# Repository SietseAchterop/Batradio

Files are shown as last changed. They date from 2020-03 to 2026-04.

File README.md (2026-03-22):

# Batradio
Software defined radio on rpi zero

The goal of this project is to create a simple sdr using a rpi-zero and a simple hat.
It should work to up to 150kHz, to be used as a ULF radio or bat detector.

## Hat for raspberry Pi

### batradio_pcb
contains a KiCad project for a hat for the rpi (zero).
It contains a 1Mbit 16 bit spi adc, mcp33131 and a 14 bit dac, mcp4821.
Also a preamplifier and lowpass filter.

Status: The prototype had the following error in the PCB design. Pins 1 and 8 of the U4, a ths4521, should be swapped and a 100nF capacitor to ground should be connected to pin 2.
This, untested, version corrects that.

Here the Schematic

And the PCB
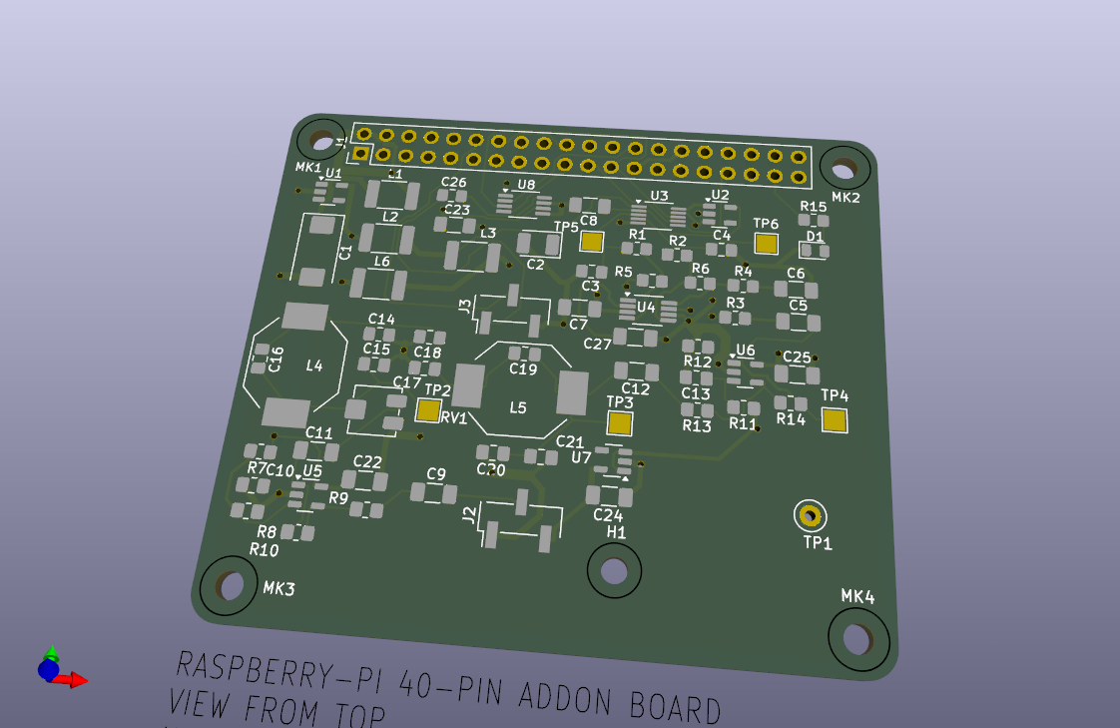
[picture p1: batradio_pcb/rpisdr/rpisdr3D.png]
PCBview


## Kernel module, a failed attempt.

Kernel module to process the data from adc and dac.
This also is work in progress.
Currently I have not been able to get the FIQ interrupt working.

### mcp331131_streaming

A variant of https://iosoft.blog/2020/11/16/streaming-analog-data-raspberry-pi/

The main changes for the 16 bit mcp33131 are:

  - Used PWM to create the CNVST pulse.
  - Writing dummy to create SCLK.
  - added -U option to send data over UDP channel.
  - DAC not used yet.
  
Basically works, but the data is partly wrong.
Also the SPI clock should be lower than 5 MHz?

## kicadlibs
My local symbols and footprints for KiCad

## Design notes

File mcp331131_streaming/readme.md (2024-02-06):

Raspberry Pi ADC data streaming

See https://iosoft.blog/streaming-analog-data-raspberry-pi for details.

This is a version using mcp33131 as ADC.
CNVCS is connected to GPIO13, PWM1
But should be GPIO12, PWM0. Forgotten why.

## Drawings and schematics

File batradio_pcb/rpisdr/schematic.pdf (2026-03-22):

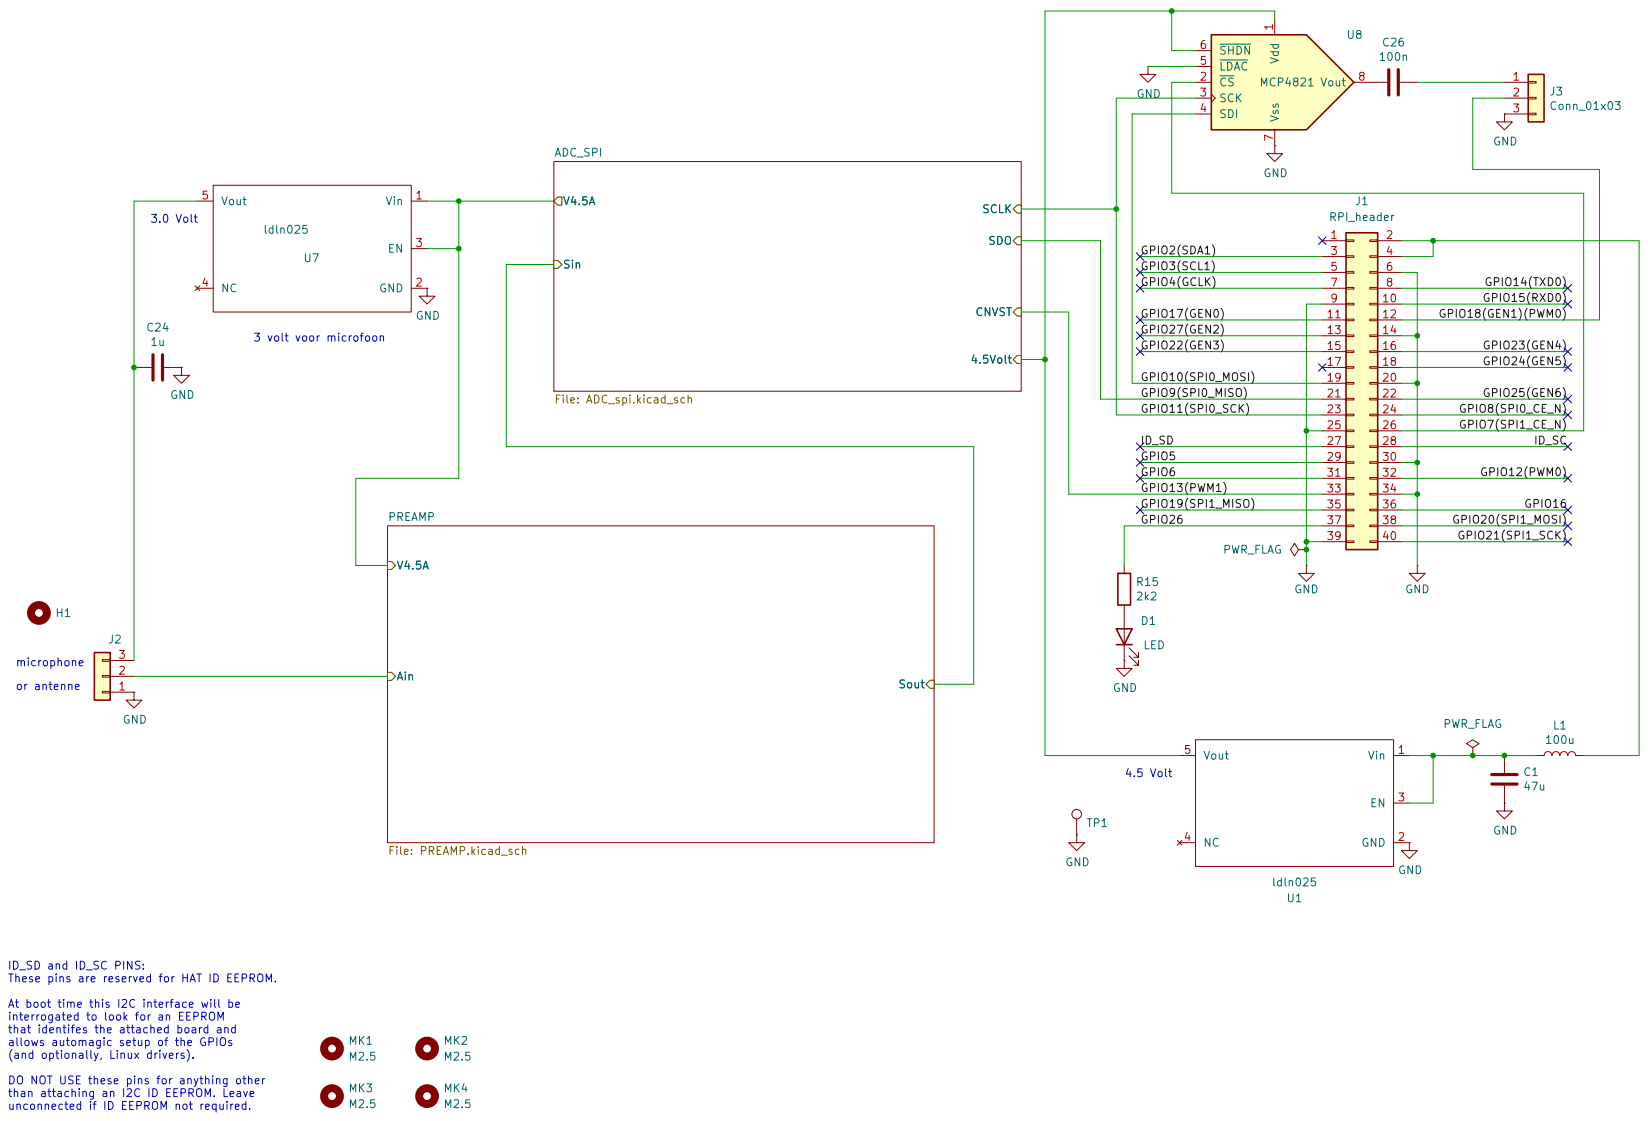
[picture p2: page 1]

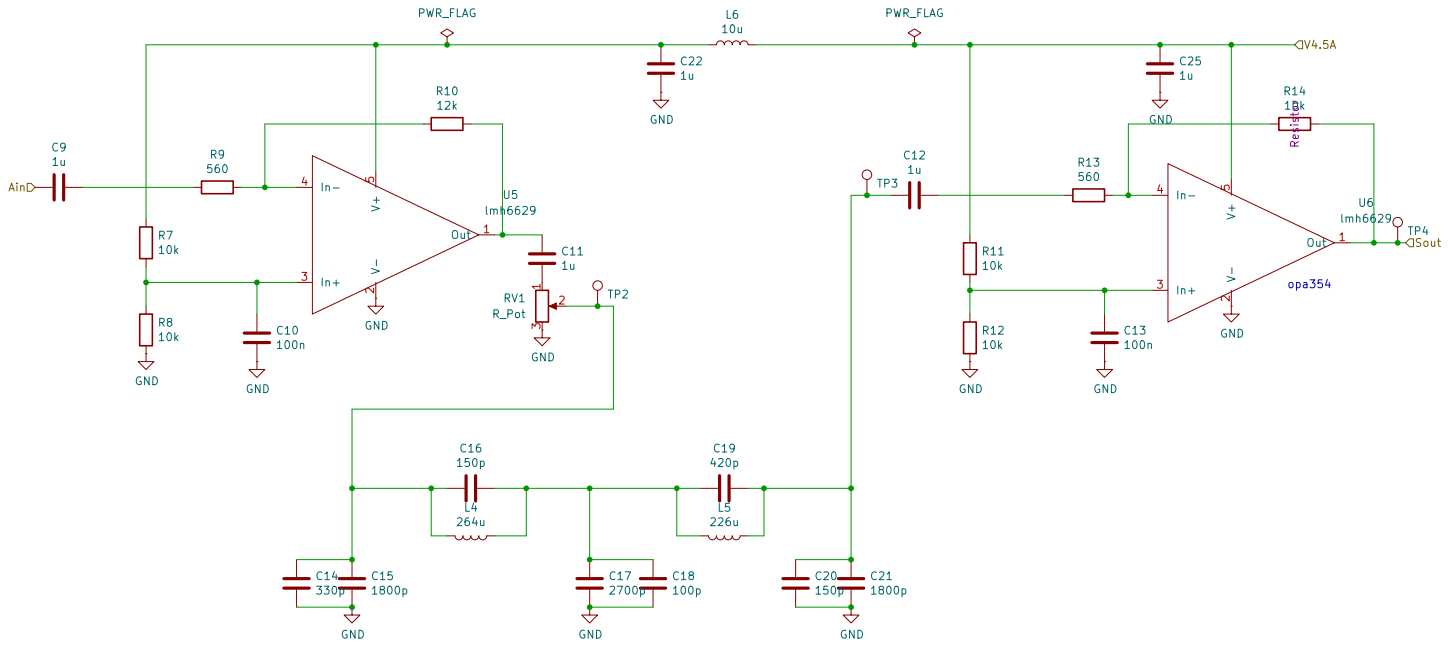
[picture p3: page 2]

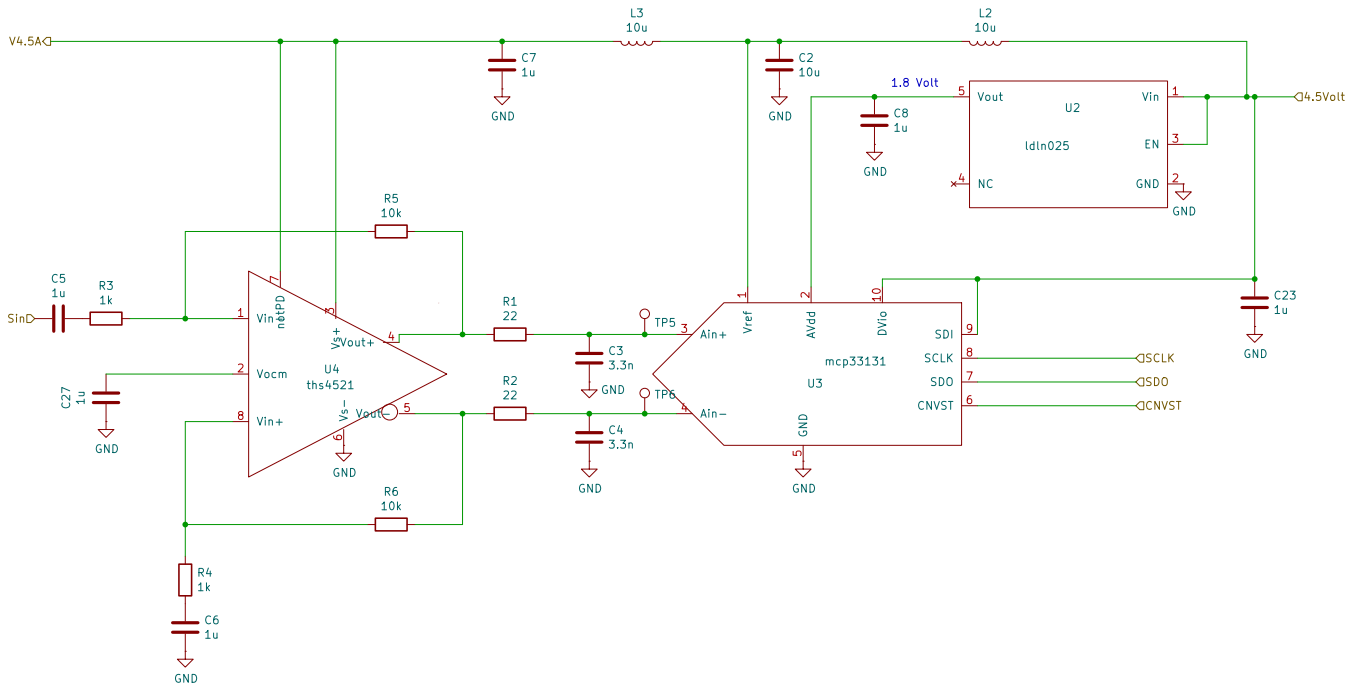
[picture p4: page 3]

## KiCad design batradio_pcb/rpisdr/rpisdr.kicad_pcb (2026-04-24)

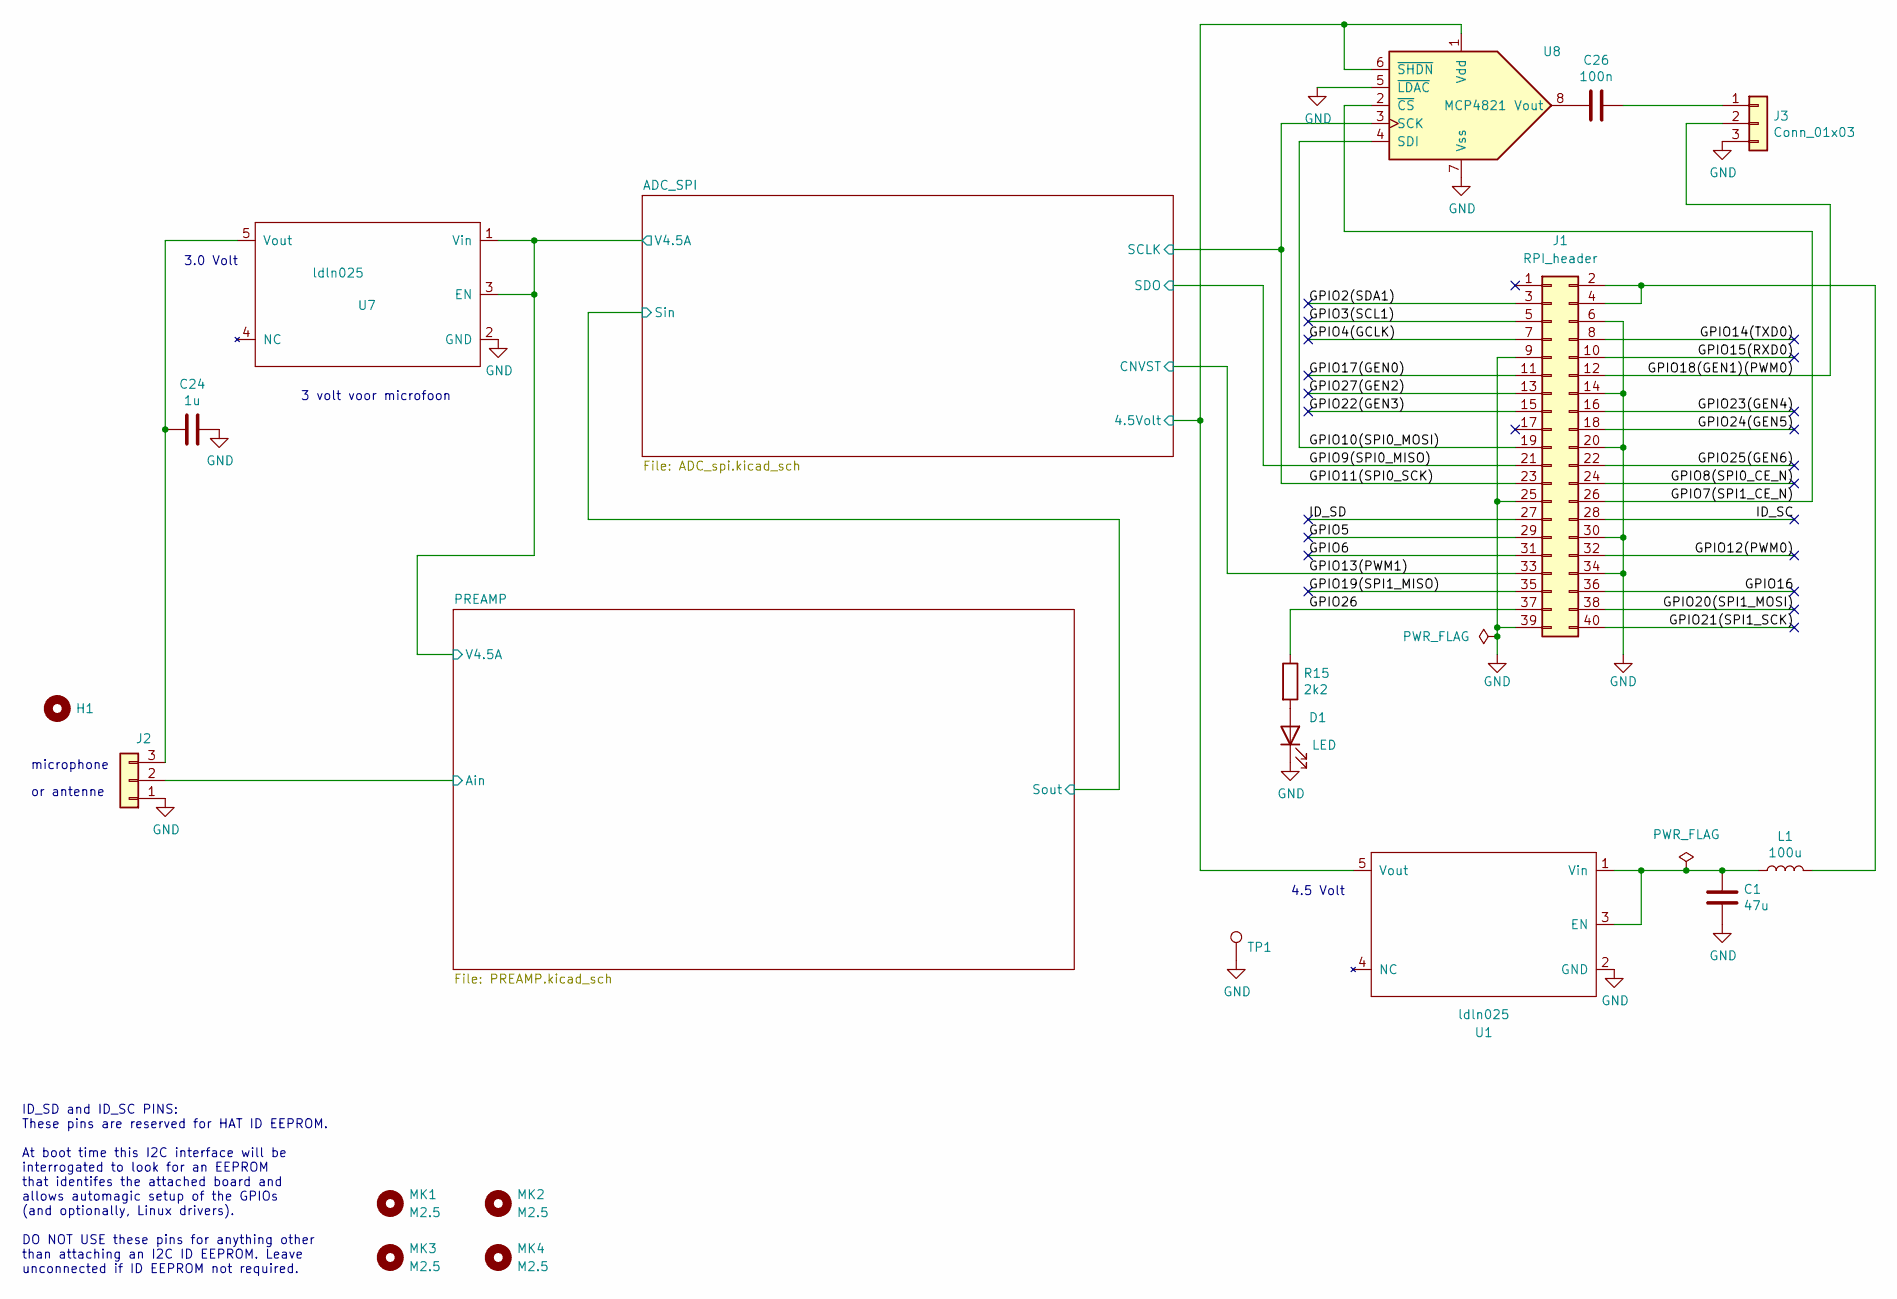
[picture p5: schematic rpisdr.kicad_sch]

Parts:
C1: 47u; CP_EIA-7343-30_AVX-N
C24: 1u; C_1206_3216Metric_Pad1.33x1.80mm_HandSolder
C26: 100n; C_0805_2012Metric_Pad1.18x1.45mm_HandSolder
D1: LED; LED_0805_2012Metric
H1: MountingHole; MountingHole_2.5mm
J1: RPI_header; PinHeader_2x20_P2.54mm_Vertical
J2, J3: Conn_01x03; PinHeader_1x03_P2.54mm_Vertical_SMD_Pin1Left
L1: 100u; L_1812_4532Metric_Pad1.30x3.40mm_HandSolder
MK1, MK2, MK3, MK4: M2.5; MountingHole_2.7mm_M2.5
R15: 2k2; R_0805_2012Metric_Pad1.20x1.40mm_HandSolder
TP1: TestPoint; TestPoint_Loop_D2.50mm_Drill1.0mm
U1, U7: ldln025; SOT-23-5
U8: MCP4821; MSOP-8_3x3mm_P0.65mm

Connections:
/ADC_SPI/4.5Volt: U1.5 (Vout), U8.1 (Vdd), U8.6 (~SHDN); also elsewhere on the board
/ADC_SPI/V4.5A: U7.1 (Vin), U7.3 (EN); also elsewhere on the board
/GPIO2(SDA1): J1.3
/GPIO3(SCL1): J1.5
/GPIO4(GCLK): J1.7
/GPIO5: J1.29
/GPIO6: J1.31
/GPIO7(SPI1_CE_N): J1.26, U8.2 (~CS)
/GPIO8(SPI0_CE_N): J1.24
/GPIO9(SPI0_MISO): J1.21; also elsewhere on the board
/GPIO10(SPI0_MOSI): J1.19, U8.4 (SDI)
/GPIO11(SPI0_SCK): J1.23, U8.3 (SCK); also elsewhere on the board
/GPIO12(PWM0): J1.32
/GPIO13(PWM1): J1.33; also elsewhere on the board
/GPIO14(TXD0): J1.8
/GPIO15(RXD0): J1.10
/GPIO16: J1.36
/GPIO17(GEN0): J1.11
/GPIO18(GEN1)(PWM0): J1.12, J3.2
/GPIO19(SPI1_MISO): J1.35
/GPIO20(SPI1_MOSI): J1.38
/GPIO21(SPI1_SCK): J1.40
/GPIO22(GEN3): J1.15
/GPIO23(GEN4): J1.16
/GPIO24(GEN5): J1.18
/GPIO25(GEN6): J1.22
/GPIO26: J1.37, R15.1
/GPIO27(GEN2): J1.13
/ID_SC: J1.28
/ID_SD: J1.27
/PREAMP/Ain: J2.2; also elsewhere on the board
GND: C1.2, C24.1, D1.1 (K), J1.6, J1.9, J1.14, J1.20, J1.25, J1.30, J1.34, J1.39, J2.1, J3.3, TP1.1, U1.2 (GND), U7.2 (GND), U8.5 (~LDAC), U8.7 (Vss); also elsewhere on the board
unnamed: D1.2 (A), R15.2
unnamed: J1.2, J1.4, L1.2
unnamed: C24.2, J2.3, U7.5 (Vout)
unnamed: C26.1, J3.1
unnamed: C1.1, L1.1, U1.1 (Vin), U1.3 (EN)
unnamed: C26.2, U8.8 (Vout)

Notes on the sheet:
microphone
or antenne
ID_SD and ID_SC PINS: These pins are reserved for HAT ID EEPROM. At boot time this I2C interface will be interrogated to look for an EEPROM that identifes the attached board and allows automagic setup of the GPIOs (and optionally, Linux drivers). DO NOT USE these pins for anything other than attach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
3 volt voor microfoon
3.0 Volt
4.5 Volt

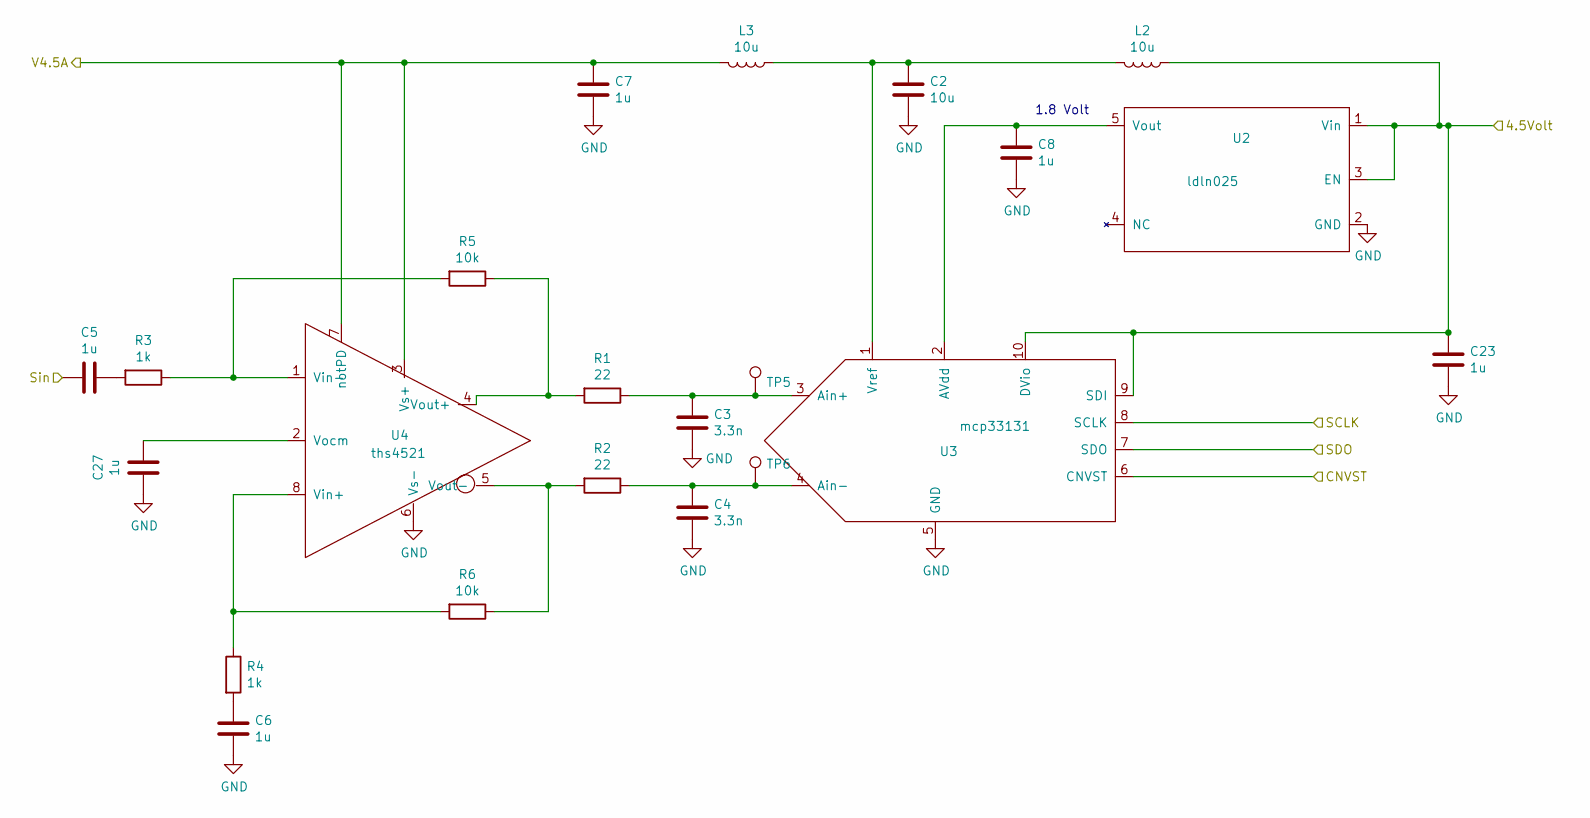
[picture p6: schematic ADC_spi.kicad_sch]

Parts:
C2: 10u; CP_EIA-3528-12_Kemet-T
C3, C4: 3.3n; C_0805_2012Metric_Pad1.18x1.45mm_HandSolder
C5, C6, C7, C8, C23, C27: 1u; C_1206_3216Metric_Pad1.33x1.80mm_HandSolder
L2, L3: 10u; L_1812_4532Metric_Pad1.30x3.40mm_HandSolder
R1, R2: 22; R_0805_2012Metric_Pad1.20x1.40mm_HandSolder
R3, R4: 1k; R_0805_2012Metric_Pad1.20x1.40mm_HandSolder
R5, R6: 10k; R_0805_2012Metric_Pad1.20x1.40mm_HandSolder
TP5, TP6: TestPoint; TestPoint_Pad_2.0x2.0mm
U2: ldln025; SOT-23-5
U3: mcp33131; MSOP-10_3x3mm_P0.5mm
U4: ths4521; VSSOP-8_3x3mm_P0.65mm

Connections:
/ADC_SPI/4.5Volt: C23.1, L2.1, U2.1 (Vin), U2.3 (EN), U3.9 (SDI), U3.10 (DVio); also elsewhere on the board
/ADC_SPI/Sin: C5.2; also elsewhere on the board
/ADC_SPI/V4.5A: C7.1, L3.2, U4.3 (Vs+), U4.7 (notPD); also elsewhere on the board
/GPIO9(SPI0_MISO): U3.7 (SDO); also elsewhere on the board
/GPIO11(SPI0_SCK): U3.8 (SCLK); also elsewhere on the board
/GPIO13(PWM1): U3.6 (CNVST); also elsewhere on the board
GND: C2.2, C3.2, C4.2, C6.2, C7.2, C8.2, C23.2, C27.2, U2.2 (GND), U3.5 (GND), U4.6 (Vs-); also elsewhere on the board
unnamed: C5.1, R3.2
unnamed: C6.1, R4.2
unnamed: C8.1, U2.5 (Vout), U3.2 (AVdd)
unnamed: C3.1, R1.1, TP5.1, U3.3 (Ain+)
unnamed: C4.1, R2.1, TP6.1, U3.4 (Ain-)
unnamed: C2.1, L2.2, L3.1, U3.1 (Vref)
unnamed: R4.1, R6.2, U4.8 (Vin+)
unnamed: R3.1, R5.2, U4.1 (Vin-)
unnamed: C27.1, U4.2 (Vocm)
unnamed: R1.2, R5.1, U4.4 (Vout+)
unnamed: R2.2, R6.1, U4.5 (Vout-)

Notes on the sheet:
1.8 Volt

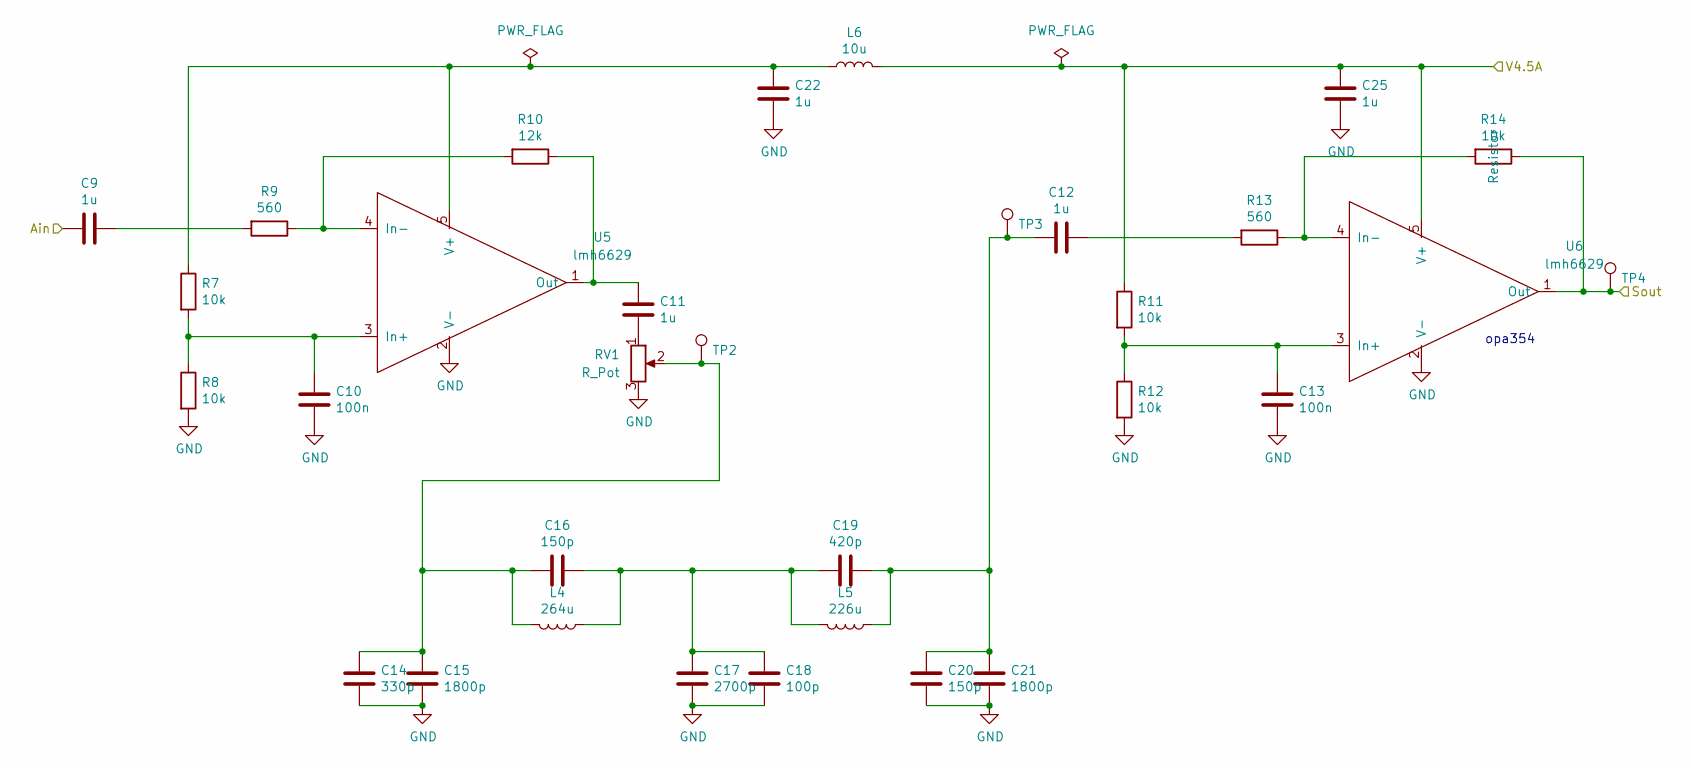
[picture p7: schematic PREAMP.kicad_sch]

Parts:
C9, C11, C12, C22, C25: 1u; C_1206_3216Metric_Pad1.33x1.80mm_HandSolder
C10, C13: 100n; C_0805_2012Metric_Pad1.18x1.45mm_HandSolder
C14: 330p; C_0805_2012Metric_Pad1.18x1.45mm_HandSolder
C15, C21: 1800p; C_0805_2012Metric_Pad1.18x1.45mm_HandSolder
C16, C20: 150p; C_0805_2012Metric_Pad1.18x1.45mm_HandSolder
C17: 2700p; C_0805_2012Metric_Pad1.18x1.45mm_HandSolder
C18: 100p; C_0805_2012Metric_Pad1.18x1.45mm_HandSolder
C19: 420p; C_0805_2012Metric_Pad1.18x1.45mm_HandSolder
L4: 264u; L_Neosid_Ms95
L5: 226u; L_Neosid_Ms95
L6: 10u; L_1812_4532Metric_Pad1.30x3.40mm_HandSolder
R7, R8, R11, R12, R14: 10k; R_0805_2012Metric_Pad1.20x1.40mm_HandSolder
R9, R13: 560; R_0805_2012Metric_Pad1.20x1.40mm_HandSolder
R10: 12k; R_0805_2012Metric_Pad1.20x1.40mm_HandSolder
RV1: R_Pot; Potentiometer_Bourns_3214J_Horizontal
TP2, TP3, TP4: TestPoint; TestPoint_Pad_2.0x2.0mm
U5, U6: lmh6629; SOT-23-5

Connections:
/ADC_SPI/Sin: R14.1, TP4.1, U6.1 (Out); also elsewhere on the board
/ADC_SPI/V4.5A: C25.1, L6.2, R11.1, U6.5 (V+); also elsewhere on the board
/PREAMP/Ain: C9.2; also elsewhere on the board
GND: C10.2, C13.2, C14.2, C15.2, C17.2, C18.2, C20.2, C21.2, C22.2, C25.2, R8.2, R12.2, RV1.3, U5.2 (V-), U6.2 (V-); also elsewhere on the board
unnamed: C9.1, R9.2
unnamed: C11.2, RV1.1
unnamed: C12.1, R13.2
unnamed: C12.2, C19.1, C20.1, C21.1, L5.1, TP3.1
unnamed: C14.1, C15.1, C16.2, L4.2, RV1.2, TP2.1
unnamed: C16.1, C17.1, C18.1, C19.2, L4.1, L5.2
unnamed: C10.1, R7.2, R8.1, U5.3 (In+)
unnamed: R9.1, R10.2, U5.4 (In-)
unnamed: C11.1, R10.1, U5.1 (Out)
unnamed: C22.1, L6.1, R7.1, U5.5 (V+)
unnamed: C13.1, R11.2, R12.1, U6.3 (In+)
unnamed: R13.1, R14.2, U6.4 (In-)

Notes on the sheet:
opa354

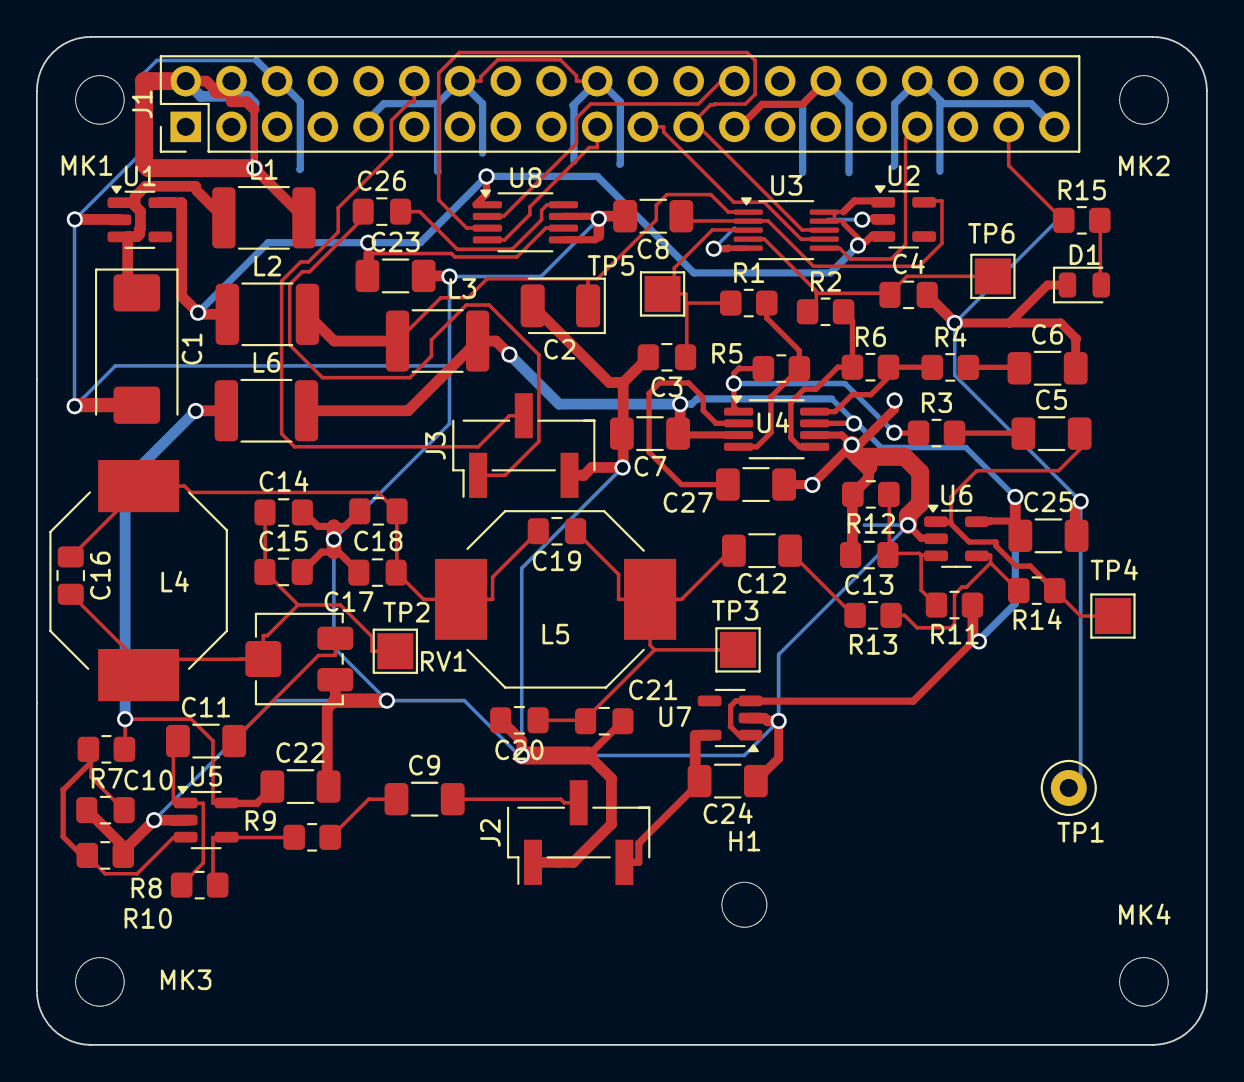
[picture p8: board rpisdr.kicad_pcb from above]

Board: 2 copper layers, 65.0 x 56.0 mm, 72 parts (0 on the bottom side), 41 nets.

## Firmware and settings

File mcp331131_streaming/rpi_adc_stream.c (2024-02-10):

// Raspberry Pi MCP3202 ADC streaming interface; see https://iosoft.blog for details
//
// Version to use MCP33131 and PWM1/GPIO13
/*
SPI_FREQ 10000000
sudo ./rpi_adc_stream -n 1000 -r 300000 -s /tmp/adc.fifo
  timing past, alleen af en toe vertraging van  spi_clk. Er is een marge van 1 usec.
     - maar af en toe langer. Probleem?
     - vrij veel overruns bij: cat /dev/adc.fifo >/dev/null
  Dus net voldoende, 150 kHz, vleermuizen gaan tot 120 kHz.

Alternatively via UDP with -U <ip_number>
  sudo ./rpi_adc_stream -n 1000 -r 300000 -u 192.168.178.59

 */

//
// Copyright (c) 2020 Jeremy P Bentham
//
// Licensed under the Apache License, Version 2.0 (the "License");
// you may not use this file except in compliance with the License.
// You may obtain a copy of the License at
//
//     http://www.apache.org/licenses/LICENSE-2.0
//
// Unless required by applicable law or agreed to in writing, software
// distributed under the License is distributed on an "AS IS" BASIS,
// WITHOUT WARRANTIES OR CONDITIONS OF ANY KIND, either express or implied.
// See the License for the specific language governing permissions and
// limitations under the License.
//
// v0.20 JPB 16/11/20 Tidied up for first Github release

#include <stdint.h>
#include <stdlib.h>
#include <unistd.h>
#include <stdio.h>
#include <signal.h>
#include <string.h>
#include <ctype.h>
#include <sys/stat.h>
#include <errno.h>
#include <fcntl.h>
#include <poll.h>
#include "rpi_dma_utils.h"

#include <netdb.h>
#include <sys/types.h>
#include <sys/socket.h>
#include <netinet/in.h>
#include <arpa/inet.h>
#include <math.h>

#define VERSION "0.20"

#define SAMPLE_RATE     100     // Default & max sample rate (samples/sec)
#define MAX_SAMPLE_RATE 50000

// PWM definitions: divisor, and reload value
#define PWM_FREQ        4000000
#define PWM_VALUE       2

// ADC sample size (2 bytes)
#define ADC_RAW_LEN     2

// ADC and DAC chip-enables
#define ADC_CE_NUM      0
#define DAC_CE_NUM      1

// Definitions for 2 bytes per ADC sample (all 16-bit)
#define ADC_VOLTAGE(n)  (((n) * 3.3) / 65536.0)
// swap 2 lower bytes
#define ADC_RAW_VAL(d)  (((uint16_t)(d)<<8 | (uint16_t)(d)>>8))

// Non-cached memory size
#define MAX_SAMPS       1024
#define SAMP_SIZE       4
#define BUFF_LEN        (MAX_SAMPS * SAMP_SIZE)
#define MAX_BUFFS       2
#define VC_MEM_SIZE     (PAGE_SIZE + (BUFF_LEN * MAX_BUFFS))

// DMA control block macros
#define NUM_CBS         12
#define GPIO(r)         BUS_GPIO_REG(r)
#define REG(r, a)       REG_BUS_ADDR(r, a)
#define MEM(m, a)       MEM_BUS_ADDR(m, a)
#define CBS(n)          MEM_BUS_ADDR(mp, &dp->cbs[(n)])

// DMA transfer information for PWM and SPI
#define PWM_TI          (DMA_DEST_DREQ | (DMA_PWM_DREQ << 16)    | DMA_WAIT_RESP)
#define SPI_RX_TI       (DMA_SRCE_DREQ | (DMA_SPI_RX_DREQ << 16) | DMA_WAIT_RESP | DMA_CB_DEST_INC)
#define SPI_TX_TI       (DMA_DEST_DREQ | (DMA_SPI_TX_DREQ << 16) | DMA_WAIT_RESP | DMA_CB_SRCE_INC)

// SPI clock frequency
#define MIN_SPI_FREQ    10000
#define MAX_SPI_FREQ    20000000
//#define SPI_FREQ        10000000
#define SPI_FREQ        1000000

// SPI 0 pin definitions
#define SPI0_CE0_PIN    8
#define SPI0_CE1_PIN    7
#define SPI0_MISO_PIN   9
#define SPI0_MOSI_PIN   10
#define SPI0_SCLK_PIN   11

// SPI registers and constants
#define SPI0_BASE       (PHYS_REG_BASE + 0x204000)
#define SPI_CS          0x00
#define SPI_FIFO        0x04
#define SPI_CLK         0x08
#define SPI_DLEN        0x0c
#define SPI_DC          0x14
#define SPI_FIFO_CLR    (3 << 4)
#define SPI_RX_FIFO_CLR (2 << 4)
#define SPI_TX_FIFO_CLR (1 << 4)
#define SPI_TFR_ACT     (1 << 7)
#define SPI_DMA_EN      (1 << 8)
#define SPI_AUTO_CS     (1 << 11)
#define SPI_RXD         (1 << 17)
#define SPI_CE0         0
#define SPI_CE1         1

// SPI register strings
char *spi_regstrs[] = {"CS", "FIFO", "CLK", "DLEN", "LTOH", "DC", ""};

// Microsecond timer
#define USEC_BASE       (PHYS_REG_BASE + 0x3000)
#define USEC_TIME       0x04
uint32_t usec_start;

// Buffer for streaming output, and raw Rx data
#define STREAM_BUFFLEN  10000
char stream_buff[STREAM_BUFFLEN];
uint32_t rx_buff[MAX_SAMPS];

// fcntl constant to get free FIFO length
#define F_GETPIPE_SZ    1032

#define LED_PIN        14

// Virtual memory pointers to access peripherals & memory
extern MEM_MAP gpio_regs, dma_regs, clk_regs, pwm_regs;
MEM_MAP vc_mem, spi_regs, usec_regs;

// File descriptor for FIFO
int fifo_fd;

// Data formats for -f option
#define FMT_USEC        1

// Command-line variables
int in_chans=1, sample_count=0, sample_rate=SAMPLE_RATE;
int data_format, testmode, verbose, lockstep;
uint32_t pwm_range, samp_total, overrun_total, fifo_size;
char *fifo_name;

// UDP
int sockfd=0;
struct sockaddr_in addr_con;
int addrlen = sizeof(addr_con);
// for now
#define PORT_NO 5005
#define IP_ADDRESS "127.0.0.1"
char *ip_addr;

void terminate(int sig);
void map_devices(void);
void get_uncached_mem(MEM_MAP *mp, int size);
int adc_get_sample(int chan);
float test_pwm_frequency(MEM_MAP *mp);
float test_spi_frequency(MEM_MAP *mp);
void adc_dma_init(MEM_MAP *mp, int ns, int single);
void adc_stream_start(void);
void adc_stream_wait(void);
void adc_stream_stop(void);
int adc_stream_csv(MEM_MAP *mp, char *vals, int maxlen, int nsamp);
int adc_stream_raw(MEM_MAP *mp, char *vals, int maxlen, int nsamp, int num);
int adc_stream_packet(MEM_MAP *mp, char *vals, int maxlen, int nsamp, int num);
void dma_wait(int chan);
void do_streaming(MEM_MAP *mp, char *vals, int maxlen, int nsamp);
void do_streaming_udp(MEM_MAP *mp, char *vals, int maxlen, int nsamp, int num);
int create_fifo(char *fname);
int create_udp_channel(char *fname);
int open_fifo_write(char *fname);
int write_fifo(int fd, void *data, int dlen);
uint32_t fifo_freespace(int fd);
void destroy_fifo(char *fname, int fd);
int init_spi(int hz);
void spi_clear(void);
void spi_cnvcs(void);
void spi_xfer(uint8_t *txd, uint8_t *rxd, int len);
void spi_disable(void);
void disp_spi(void);


// Main program
int main(int argc, char *argv[])
{
    int args=0, f, val=0;
    float freq;

    printf("RPi ADC streamer v" VERSION "\n");
    while (argc > ++args)               // Process command-line args
    {
        if (argv[args][0] == '-')
        {
            switch (toupper(argv[args][1]))
            {
            case 'F':                   // -F: output format
                if (args>=argc-1 || !isdigit((int)argv[args+1][0]))
                    fprintf(stderr, "Error: no format value\n");
                else
                    data_format = atoi(argv[++args]);
                break;
            case 'I':                   // -I: number of input channels
                if (args>=argc-1 || !isdigit((int)argv[args+1][0]))
                    fprintf(stderr, "Error: no input chan count\n");
                else
                    in_chans = atoi(argv[++args]);
                break;
            case 'L':                   // -L: lockstep streaming
                lockstep = 1;
                break;
            case 'N':                   // -N: number of samples per block
                if (args>=argc-1 || !isdigit((int)argv[args+1][0]) ||
                    (sample_count = atoi(argv[++args])) < 1)
                    fprintf(stderr, "Error: no sample count\n");
                else if (sample_count > MAX_SAMPS)
                {
                    fprintf(stderr, "Error: maximum sample count %u\n", MAX_SAMPS);
                    sample_count = MAX_SAMPS;
                }
                break;
            case 'R':                   // -R: sample rate (samples/sec)
                if (args>=argc-1 || !isdigit((int)argv[args+1][0]))
                    fprintf(stderr, "Error: no sample rate\n");
                else if (sample_rate > MAX_SAMPLE_RATE)
                    fprintf(stderr, "Error: exceeded max sample rate\n");
                else
                    sample_rate = atoi(argv[++args]);
                break;
            case 'S':                   // -S: stream into named pipe (FIFO)
                if (args>=argc-1 || !argv[args+1][0])
                    fprintf(stderr, "Error: no FIFO name\n");
                else
                    fifo_name = argv[++args];
                break;
            case 'T':                   // -T: test mode
                testmode = 1;
                break;
            case 'U':                   // -U: stream into UDP channel
                if (args>=argc-1 || !argv[args+1][0])
                    fprintf(stderr, "Error: no IP address\n");
                else
                    ip_addr = argv[++args];
                break;
            case 'V':                   // -V: verbose mode (display hex data)
                verbose = 1;
                break;
            default:
                printf("Error: unrecognised option '%s'\n", argv[args]);
                exit(1);
            }
        }
    }
    map_devices();
    map_uncached_mem(&vc_mem, VC_MEM_SIZE);
    signal(SIGINT, terminate);
    pwm_range = (PWM_FREQ * 2) / sample_rate;
    f = init_spi(SPI_FREQ);

    gpio_mode(LED_PIN, GPIO_OUT);

    if (testmode)
    {
        printf("Testing %1.3f MHz SPI frequency: ", f/1e6);
	freq = test_spi_frequency(&vc_mem);
        printf("%7.3f MHz\n", freq);
        printf("Testing %5u Hz  PWM frequency: ", sample_rate);
        freq = test_pwm_frequency(&vc_mem);
        printf("%7.3f Hz\n", freq);
    }
    else if (sample_count == 0)
    {
        printf("SPI frequency %u Hz\n", f);
        val = adc_get_sample(0);
        printf("ADC value %u = %4.3fV\n", val, ADC_VOLTAGE(val));
    }
    else if (fifo_name)
    {
        if (create_fifo(fifo_name))
        {
            printf("Created FIFO '%s'\n", fifo_name);
            printf("Streaming %u samples per block at %u S/s %s\n",
                   sample_count, sample_rate, lockstep ? "(lockstep)" : "");
            adc_dma_init(&vc_mem, sample_count, 0);
            adc_stream_start();
            while (1)
                do_streaming(&vc_mem, stream_buff, STREAM_BUFFLEN, sample_count);
        }
    }
    else if (ip_addr)
    {
        if (create_udp_channel(ip_addr))
        {
            printf("Opened UDP channel to port 5005 on '%s'\n", ip_addr);
            printf("Streaming %u samples per block at %u S/s %s\n",
                   sample_count, sample_rate, lockstep ? "(lockstep)" : "");
            adc_dma_init(&vc_mem, sample_count, 0);
            adc_stream_start();
	    int  num = 0;
            while (1) {
	      do_streaming_udp(&vc_mem, stream_buff, STREAM_BUFFLEN, sample_count, num);
	      num++;
	    }
        }
    }
    else
    {
        printf("Reading %u samples at %u S/s\n", sample_count, sample_rate);
        adc_dma_init(&vc_mem, sample_count, 1);
        adc_stream_start();
        adc_stream_wait();
        adc_stream_stop();
        adc_stream_csv(&vc_mem, stream_buff, STREAM_BUFFLEN, sample_count);
        printf("%s", stream_buff);
    }
    terminate(0);
}

// Catastrophic failure in initial setup
void fail(char *s)
{
    printf(s);
    terminate(0);
}

// Free memory & peripheral mapping and exit
void terminate(int sig)
{
    printf("Closing\n");
    spi_disable();
    stop_dma(DMA_CHAN_A);
    stop_dma(DMA_CHAN_B);
    stop_dma(DMA_CHAN_C);
    unmap_periph_mem(&vc_mem);
    unmap_periph_mem(&usec_regs);
    unmap_periph_mem(&pwm_regs);
    unmap_periph_mem(&clk_regs);
    unmap_periph_mem(&spi_regs);
    unmap_periph_mem(&dma_regs);
    unmap_periph_mem(&gpio_regs);
    if (fifo_name)
        destroy_fifo(fifo_name, fifo_fd);
    if (samp_total)
        printf("Total samples %u, overruns %u\n", samp_total, overrun_total);
    exit(0);
}

// Map GPIO, DMA and SPI registers into virtual mem (user space)
// If any of these fail, program will be terminated
void map_devices(void)
{
    map_periph(&gpio_regs, (void *)GPIO_BASE, PAGE_SIZE);
    map_periph(&dma_regs, (void *)DMA_BASE, PAGE_SIZE);
    map_periph(&spi_regs, (void *)SPI0_BASE, PAGE_SIZE);
    map_periph(&clk_regs, (void *)CLK_BASE, PAGE_SIZE);
    map_periph(&pwm_regs, (void *)PWM_BASE, PAGE_SIZE);
    map_periph(&usec_regs, (void *)USEC_BASE, PAGE_SIZE);
}

// Get uncached memory
 void get_uncached_mem(MEM_MAP *mp, int size)
{
    if (!map_uncached_mem(mp, size))
        fail("Error: can't allocate uncached memory\n");
}

// Fetch single sample from ADC channel 0 or 1
#define BIG 10000
int adc_get_sample(int chan)
{
    uint8_t txdata[ADC_RAW_LEN] = {0, 0}; // dummy value
    uint8_t rxdata[ADC_RAW_LEN];

    int16_t filebuf[BIG];

    FILE *f = fopen("adc.data", "wb");
    printf("Dumping to adc.data\n");

    gpio_set(PWM_PIN, GPIO_OUT, GPIO_NOPULL);
    gpio_out(PWM_PIN, 0);
    uint32_t csval = *REG32(spi_regs, SPI_CS);
    while (1) {
      for (int x=0; x<BIG; x++) {
	spi_cnvcs();

	// set transfer active
	*REG32(spi_regs, SPI_CS) = csval | 0x80 ;
	spi_xfer(txdata, rxdata, ADC_RAW_LEN);
	/*
	  for (int i=0; i<ADC_RAW_LEN; i++)
	      printf("%02X ", rxdata[i]);
          int16_t data =   ((rxdata[0]) << 8) | rxdata[1];
          printf("     %d\n", data);
	*/
	// kan dit niet slimmer?
	int16_t data =   ((rxdata[0]) << 8) | rxdata[1];
	filebuf[x] = data;
	usleep(3);
	// staat het nog active?
      }
      // copy to file
      fwrite(filebuf, sizeof(int16_t), sizeof(filebuf), f);
      break;
    }
    printf("Next portion to file.  %d   %d\n", sizeof(int16_t), sizeof(filebuf));
    fclose(f);
    sync();
    
    if (verbose)
    {
        for (int i=0; i<ADC_RAW_LEN; i++)
            printf("%02X ", rxdata[i]);
        printf("\n");
    }
    return(ADC_RAW_VAL(*(uint16_t *)rxdata));
}

// Definitions for SPI frequency test
#define SPI_TEST_TI  (DMA_DEST_DREQ | (DMA_SPI_TX_DREQ << 16) | DMA_WAIT_RESP  | DMA_CB_SRCE_INC)
#define TEST_NSAMPS  10

typedef struct {
    DMA_CB cbs[NUM_CBS];
    uint32_t txd[TEST_NSAMPS], val;
    volatile uint32_t usecs[2];
} TEST_DMA_DATA;

// Test SPI frequency
float test_spi_frequency(MEM_MAP *mp)
{
    TEST_DMA_DATA *dp=mp->virt;
    TEST_DMA_DATA dma_data = {
        .txd = {0,0,0,0,0,0,0,0,0,0}, .usecs = {0, 0},
        .cbs = {
        // Tx output: 2 initial transfers, then 10 timed transfers
            {SPI_TEST_TI, MEM(mp, dp->txd), REG(spi_regs, SPI_FIFO),           2*4, 0, CBS(1), 0}, // 0
            {SPI_TEST_TI, REG(usec_regs, USEC_TIME), MEM(mp, &dp->usecs[0]),     4, 0, CBS(2), 0}, // 1
            {SPI_TEST_TI, MEM(mp, dp->txd), REG(spi_regs, SPI_FIFO), TEST_NSAMPS*4, 0, CBS(3), 0}, // 2
            {SPI_TEST_TI, REG(usec_regs, USEC_TIME), MEM(mp, &dp->usecs[1]),     4, 0, 0,      0}, // 3
        }
    };
    memcpy(dp, &dma_data, sizeof(dma_data));                // Copy DMA data into uncached memory
    *REG32(spi_regs, SPI_DC) = (8<<24)|(1<<16)|(8<<8)|1;    // Set DMA priorities
    *REG32(spi_regs, SPI_CS) = SPI_FIFO_CLR;                // Clear SPI FIFOs
    start_dma(mp, DMA_CHAN_A, &dp->cbs[0], 0);              // Start SPI Tx DMA
    *REG32(spi_regs, SPI_DLEN) = (TEST_NSAMPS + 2) * 4;     // Set data length, and SPI flags
    *REG32(spi_regs, SPI_CS) = SPI_TFR_ACT | SPI_DMA_EN;
    dma_wait(DMA_CHAN_A);                                   // Wait until complete
    *REG32(spi_regs, SPI_CS) = SPI_FIFO_CLR;                // Clear accumulated Rx data
    return(dp->usecs[1] > dp->usecs[0] ?
           32.0 * TEST_NSAMPS / (dp->usecs[1] - dp->usecs[0]) : 0);
}

// Test PWM frequency
float test_pwm_frequencyXX(MEM_MAP *mp)
{
    init_pwm(PWM_FREQ, pwm_range, PWM_VALUE);               // Initialise PWM    
    start_pwm();                                            // Start PWM
    usleep(50000);
    //    stop_pwm();                                             // Stop PWM
    return(0.123);
}

float test_pwm_frequency(MEM_MAP *mp)
{
    TEST_DMA_DATA *dp=mp->virt;
    TEST_DMA_DATA dma_data = {
        .val = pwm_range, .usecs = {0, 0},
        .cbs = {
        // Tx output: 2 initial transfers, then timed transfer
            {PWM_TI, MEM(mp, &dp->val),         REG(pwm_regs, PWM_FIF1), 4, 0, CBS(1), 0}, // 0
            {PWM_TI, MEM(mp, &dp->val),         REG(pwm_regs, PWM_FIF1), 4, 0, CBS(2), 0}, // 1
            {PWM_TI, REG(usec_regs, USEC_TIME), MEM(mp, &dp->usecs[0]),  4, 0, CBS(3), 0}, // 2
            {PWM_TI, MEM(mp, &dp->val),         REG(pwm_regs, PWM_FIF1), 4, 0, CBS(4), 0}, // 3
            {PWM_TI, REG(usec_regs, USEC_TIME), MEM(mp, &dp->usecs[1]),  4, 0, 0,      0}, // 4
        }
    };
    memcpy(dp, &dma_data, sizeof(dma_data));                // Copy DMA data into uncached memory
    init_pwm(PWM_FREQ, pwm_range, PWM_VALUE);               // Initialise PWM
    *REG32(pwm_regs, PWM_DMAC) = PWM_DMAC_ENAB | PWM_DMAC_TH; // Enable PWM DMA
    start_dma(mp, DMA_CHAN_A, &dp->cbs[0], 0);              // Start DMA
    start_pwm();                                            // Start PWM
    dma_wait(DMA_CHAN_A);                                   // Wait until complete
    stop_pwm();                                             // Stop PWM
    return(dp->usecs[1] > dp->usecs[0] ? 1e6 / (dp->usecs[1] - dp->usecs[0]) : 0);
}

typedef struct {
    DMA_CB cbs[NUM_CBS];
  uint32_t samp_size, pwm_val, adc_csd, txd[2], pindata;
    volatile uint32_t usecs[2], states[2], rxd1[MAX_SAMPS], rxd2[MAX_SAMPS];
} ADC_DMA_DATA;

// Initialise PWM-paced DMA for ADC sampling
//  send data only to get the clock signal!

void adc_dma_init(MEM_MAP *mp, int nsamp, int single)
{
    ADC_DMA_DATA *dp=mp->virt;
    ADC_DMA_DATA dma_data = {
      // -2 creates the CNVCS pulse, 240 nsec
        .pindata = 1<<LED_PIN,
        .samp_size = 2, .pwm_val = pwm_range-PWM_VALUE, .txd={0xd0, in_chans>1 ? 0xf0 : 0xd0},
        .adc_csd = SPI_TFR_ACT | SPI_DMA_EN | ADC_CE_NUM,
	//	.adc_csd = SPI_TFR_ACT | SPI_DMA_EN | SPI_FIFO_CLR | ADC_CE_NUM,
        .usecs = {0, 0}, .states = {0, 0}, .rxd1 = {0}, .rxd2 = {0},
        .cbs = {
        // Rx input: read data from usec clock and SPI, into 2 ping-pong buffers
            {SPI_RX_TI, REG(usec_regs, USEC_TIME), MEM(mp, &dp->usecs[0]),  4, 0, CBS(1), 0}, // 0
            {SPI_RX_TI, REG(spi_regs, SPI_FIFO),   MEM(mp, dp->rxd1), nsamp*4, 0, CBS(2), 0}, // 1
            {SPI_RX_TI, REG(spi_regs, SPI_CS),     MEM(mp, &dp->states[0]), 4, 0, CBS(3), 0}, // 2
            {SPI_RX_TI, REG(usec_regs, USEC_TIME), MEM(mp, &dp->usecs[1]),  4, 0, CBS(4), 0}, // 3
            {SPI_RX_TI, REG(spi_regs, SPI_FIFO),   MEM(mp, dp->rxd2), nsamp*4, 0, CBS(5), 0}, // 4
            {SPI_RX_TI, REG(spi_regs, SPI_CS),     MEM(mp, &dp->states[1]), 4, 0, CBS(0), 0}, // 5
        // Tx output: 2 data writes to SPI for chan 0 & 1, or both chan 0
            {SPI_TX_TI, MEM(mp, dp->txd),          REG(spi_regs, SPI_FIFO), 4, 0, CBS(6), 0}, // 6  dummy data to get a clock
        // PWM ADC trigger: wait for PWM, set sample length, trigger SPI
            {PWM_TI,    MEM(mp, &dp->pwm_val),     REG(pwm_regs, PWM_FIF1), 4, 0, CBS(8), 0}, // 7
            {PWM_TI,    MEM(mp, &dp->samp_size),   REG(spi_regs, SPI_DLEN), 4, 0, CBS(9), 0}, // 8
            {PWM_TI,    MEM(mp, &dp->adc_csd),     REG(spi_regs, SPI_CS),   4, 0, CBS(7), 0}, // 9
	    /*
	    {PWM_TI,    MEM(mp, &dp->pindata),     GPIO(GPIO_CLR0),         4, 0, CBS(8), 0}, // 7
	    {PWM_TI,    MEM(mp, &dp->pindata),     GPIO(GPIO_SET0),         4, 0, CBS(11), 0}, // 11
	    */
        }
    };
    if (single)                                 // If single-shot, stop after first Rx block
        dma_data.cbs[2].next_cb = 0;
    memcpy(dp, &dma_data, sizeof(dma_data));    // Copy DMA data into uncached memory
    init_pwm(PWM_FREQ, pwm_range, PWM_VALUE);   // Initialise PWM, with DMA
    *REG32(pwm_regs, PWM_DMAC) = PWM_DMAC_ENAB | PWM_DMAC_TH;
    *REG32(spi_regs, SPI_DC) = (8<<24) | (1<<16) | (8<<8) | 1;  // Set DMA priorities
    *REG32(spi_regs, SPI_CS) = SPI_FIFO_CLR;                    // Clear SPI FIFOs
    start_dma(mp, DMA_CHAN_C, &dp->cbs[6], 0);  // Start SPI Tx DMA
    start_dma(mp, DMA_CHAN_B, &dp->cbs[0], 0);  // Start SPI Rx DMA
    start_dma(mp, DMA_CHAN_A, &dp->cbs[7], 0);  // Start PWM DMA, for SPI trigger
}

// Manage streaming output
void do_streaming(MEM_MAP *mp, char *vals, int maxlen, int nsamp)
{
    int n;

    if (!fifo_fd)
    {
        if ((fifo_fd = open_fifo_write(fifo_name)) > 0)
        {
            printf("Started streaming to FIFO '%s'\n", fifo_name);
            fifo_size = fifo_freespace(fifo_fd);
        }
    }
    if (fifo_fd)
    {
        if ((n=adc_stream_csv(mp, vals, maxlen, nsamp)) > 0)
        {
            if (!write_fifo(fifo_fd, vals, n))
            {
                printf("Stopped streaming\n");
                close(fifo_fd);
                fifo_fd = 0;
                usleep(100000);
            }
        }
        else
            usleep(10);
    }
}

// Streaming to UDP channel
void do_streaming_udp(MEM_MAP *mp, char *vals, int maxlen, int nsamp, int num) {
  int n, flags=0;

  if ((n=adc_stream_packet(mp, vals, maxlen, nsamp, num)) > 0) {
    //printf("Y, with n=%d\n",n);
    if (!sendto(sockfd, vals, n, flags, (struct sockaddr*)&addr_con, addrlen)) {
      printf("UDP error %s\n", strerror(errno));  
      // close socket?  dit gaat anders !!
      usleep(100);
    }
  }
  else {
    // goeie waarde?
    printf("N");
    usleep(100);
  }
}

// Start ADC data acquisition
void adc_stream_start(void)
{
    start_pwm();
}

// Wait until a (single) DMA cycle is complete
void adc_stream_wait(void)
{
    dma_wait(DMA_CHAN_B);
}

// Stop ADC data acquisition
void adc_stream_stop(void)
{
    stop_pwm();
}
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

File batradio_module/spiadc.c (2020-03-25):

/*
  read from  mcp33131 16 bit adc
  derived from C example from https://elinux.org/RPi_GPIO_Code_Samples
                         and gertboard examples

  Na gebruikt doet python versie het niet meer goed.
  Wat laat ik niet goed achter?
 */

#include <stdio.h>
#include <stdlib.h>
#include <fcntl.h>
#include <sys/mman.h>
#include <unistd.h>
#include <time.h>
#include <signal.h>

struct timespec st, et;

#include "spi.h"

// also for BCM2835 on rpi_zero
#define BCM2708_PERI_BASE        0x20000000
#define GPIO_BASE                (BCM2708_PERI_BASE + 0x200000) /* GPIO controller */
#define SPI0_BASE                (BCM2708_PERI_BASE + 0x204000) /* SPI0 controller */


#define PAGE_SIZE (4*1024)
#define BLOCK_SIZE (4*1024)

int  mem_fd;

// I/O access
char *gpio_mem_orig, *gpio_mem, *gpio_map;
volatile unsigned *gpio;

// GPIO setup macros. Always use INP_GPIO(x) before using OUT_GPIO(x) or SET_GPIO_ALT(x,y)
#define INP_GPIO(g) *(gpio+((g)/10)) &= ~(7<<(((g)%10)*3))
#define OUT_GPIO(g) *(gpio+((g)/10)) |=  (1<<(((g)%10)*3))
#define SET_GPIO_ALT(g,a) *(gpio+(((g)/10))) |= (((a)<=3?(a)+4:(a)==4?3:2)<<(((g)%10)*3))

#define GPIO_SET *(gpio+7)  // sets   bits which are 1 ignores bits which are 0
#define GPIO_CLR *(gpio+10) // clears bits which are 1 ignores bits which are 0

#define GET_GPIO(g) (*(gpio+13)&(1<<g)) // 0 if LOW, (1<<g) if HIGH

#define GPIO_PULL *(gpio+37) // Pull up/pull down
#define GPIO_PULLCLK0 *(gpio+38) // Pull up/pull down clock

// SPI constants, from gb_stuff
char *spi0_mem_orig, *spi0_mem, *spi0_map;
volatile unsigned *spi0;

void intHandler(int dummy) {

  printf("\n Ended with control-C\n");
  restore_io();
  exit(0);
}

int main(int argc, char **argv)
{ char dummy;
  int i, d, t;
  #define N 10000
  int arr[N];
  
  signal(SIGINT, intHandler);
  
  setup_io();
  setup_gpio();
  setup_spi();
    
 // configure CNVST
  INP_GPIO(13); // must use INP_GPIO before we can use OUT_GPIO
  OUT_GPIO(13);

  // read data
  clock_gettime(CLOCK_MONOTONIC, &st);
  i = 0;
  while(i<N) {
    // start acquisition  (700 nsec)
    GPIO_SET = 1<<13;
    short_wait(3);
    // stop acquisition
    GPIO_CLR = 1<<13;

    arr[i] = read_adc();
    short_wait(1);
    i++;
  }

  clock_gettime(CLOCK_MONOTONIC, &et);
  t = (et.tv_sec - st.tv_sec)*1000000 + (et.tv_nsec - st.tv_nsec)/1000;
  printf("elapsed %f microseconds per cycle.\n",  (float)t/(float)N);

  i = 0;
  while (i< N) {
    printf("%d\n", arr[i]);
    i++;
  }
  
  restore_io();
  return 0;

}


//
// Set up a memory regions to access GPIO
//
void setup_io()
{ unsigned long extra;
  
   /* open /dev/mem */
   if ((mem_fd = open("/dev/mem", O_RDWR|O_SYNC) ) < 0) {
      printf("can't open /dev/mem \n");
      exit(-1);
   }

   /* mmap GPIO */
   gpio_map = mmap(
      NULL,             //Any adddress in our space will do
      BLOCK_SIZE,       //Map length
      PROT_READ|PROT_WRITE,// Enable reading & writting to mapped memory
      MAP_SHARED,       //Shared with other processes
      mem_fd,           //File to map
      GPIO_BASE         //Offset to GPIO peripheral
   );

   if (gpio_map == MAP_FAILED) {
      printf("mmap error %d\n", (int)gpio_map);//errno also set!
      exit(-1);
   }

   gpio = (volatile unsigned *)gpio_map;

   /*
    * mmap SPI0
    */
   if ((spi0_mem_orig = malloc(BLOCK_SIZE + (PAGE_SIZE-1))) == NULL) {
      printf("allocation error \n");
      exit (-1);
   }
   extra = (unsigned long)spi0_mem_orig % PAGE_SIZE;
   if (extra)
     spi0_mem = spi0_mem_orig + PAGE_SIZE - extra;
   else
     spi0_mem = spi0_mem_orig;

   spi0_map = (unsigned char *)mmap(
      (caddr_t)spi0_mem,
      BLOCK_SIZE,
      PROT_READ|PROT_WRITE,
      MAP_SHARED|MAP_FIXED,
      mem_fd,
      SPI0_BASE
   );

   if ((long)spi0_map < 0) {
      printf("spi0 mmap error %d\n", spi0_map);
      exit (-1);
   }
   spi0 = (volatile unsigned *)spi0_map;

   close(mem_fd);

}

void restore_io()
{
  munmap(spi0_map,BLOCK_SIZE);
  munmap(gpio_map,BLOCK_SIZE);
  // free memory
  free(spi0_mem_orig);
  free(gpio_mem_orig);
} // restore_io

// from gb_spi.c

// For D to A we only need the SPI bus and SPI chip select B
void setup_gpio()
{
   INP_GPIO(7);  SET_GPIO_ALT(7,0);
   INP_GPIO(9);  SET_GPIO_ALT(9,0);
   INP_GPIO(10); SET_GPIO_ALT(10,0);
   INP_GPIO(11); SET_GPIO_ALT(11,0);
} // setup_gpio


void setup_spi()
{
  // Want to have 1 MHz SPI clock.
  // Assume 250 Mhz system clock
  // So divide 250MHz system clock by 250 to get 1MHz45
  SPI0_CLKSPEED = 10;   // 4 werkt ook, maar geeft met 10 al problemen met logic analyzer, dan 50 doen
  //SPI0_CLKSPEED = 125;

  // clear FIFOs and all status bits
  SPI0_CNTLSTAT = SPI0_CS_CLRALL;
  SPI0_CNTLSTAT = SPI0_CS_DONE; // make sure done bit is cleared
} // setup_spi()


void short_wait(int v)
{ int w;
  while (v--)
    for (w=0; w<10; w++)
    { w++;
      w--;
    }
}

//
// Read a value from MCP33131 adc
//
int read_adc()
{ unsigned char v1,v2;
  int status, res;
  // Set up for single ended, MS comes out first
  v1 = 0xD0;  // | (chan<<5);
  // Delay to make sure chip select is high for a short while
  short_wait(0);

  // Enable SPI interface: No SC and set activate bit
  SPI0_CNTLSTAT = SPI0_CS_CHIPSELN|SPI0_CS_ACTIVATE;

  // Write the command into the FIFO so it will
  // be transmitted out of the SPI interface to the ADC
  // We need a 16-bit transfer so we send a command byte
  // folowed by a dummy byte
  SPI0_FIFO = v1;
  SPI0_FIFO = 0; // dummy

  // wait for SPI to be ready
  // This will take about 16 micro seconds
  do {
     status = SPI0_CNTLSTAT;
  } while ((status & SPI0_CS_DONE)==0);
  SPI0_CNTLSTAT = SPI0_CS_DONE; // clear the done bit

  // Data from the ADC chip should now be in the receiver
  // read the received data
  v1 = SPI0_FIFO;
  v2 = SPI0_FIFO;
  res = (int16_t)((v1<<8) | v2);
  return res;
}

//
// Write 12 bit value to MCP4821 DAC 
//
void write_dac(int val)
{ char v1,v2,dummy;
  int status;
  val &= 0xFFF;  // force value in 12 bits

  // Build the first byte: write, channel 0 or 1 bit
  // and the 4 most significant data bits
  v1 = 0x30 | (val>>8);
  // Remain the Least Significant 8 data bits
  v2 = val & 0xFF;

  // Delay to have CS high for a short while
  short_wait(1);
  
  // Enable SPI: Use CS 1 and set activate bit
  SPI0_CNTLSTAT = SPI0_CS_CHIPSEL1|SPI0_CS_ACTIVATE;

  // send the values
  SPI0_FIFO = v1;
  SPI0_FIFO = v2;

  // wait for SPI to be ready
  // This will take about 16 micro seconds
  do {
     status = SPI0_CNTLSTAT;
  } while ((status & SPI0_CS_DONE)==0);
  SPI0_CNTLSTAT = SPI0_CS_DONE; // clear the done bit


  // For every transmit there is also data coming back
  // We MUST read that received data from the FIFO
  // even if we do not use it!
  dummy = SPI0_FIFO;
  dummy = SPI0_FIFO;
}

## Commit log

2020-03-25 Created testprogram tst5.c
    [ADC_spi.sch, PREAMP.sch, rpisdr.dsn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]
2020-04-04 Add alloctest.c
    [ADC_spi.sch]
2024-02-10 Update rpi_adc_stream
    [ADC_spi.kicad_sch, rpisdr.kicad_sch]
2026-03-22 Corrected schematic and added mykicadlibs
    [ADC_spi.kicad_sch, PREAMP.kicad_sch, rpisdr.kicad_pcb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]
2026-03-24 Corrected mylib library settings
    [ADC_spi.kicad_sch, PREAMP.kicad_sch, rpisdr.kicad_pcb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]
